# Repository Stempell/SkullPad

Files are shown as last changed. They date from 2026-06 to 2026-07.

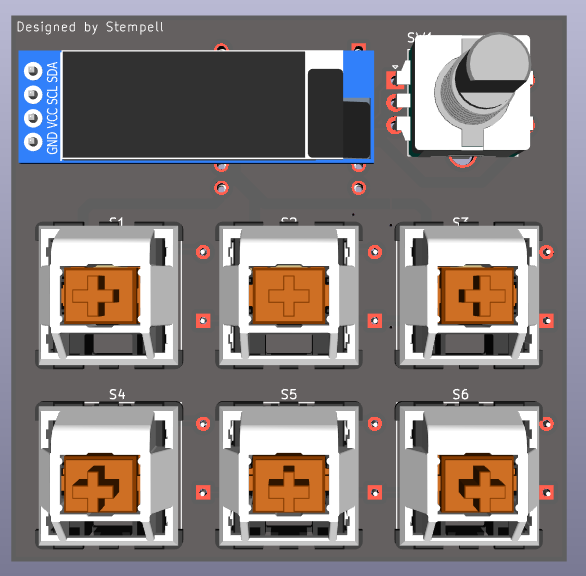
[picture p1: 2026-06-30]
Photos/Zrzut ekranu 2026-06-30 004716.png

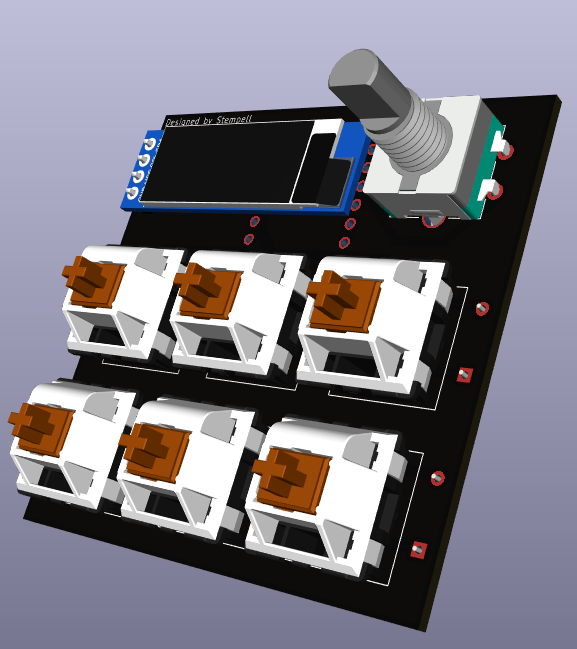
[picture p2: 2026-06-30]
Photos/Zrzut ekranu 2026-06-30 004732.png

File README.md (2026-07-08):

# SkullPad
Im buliding this macropad for Hack Club's stardance program! I'll be using it for shortcuts and volume controll.
Here's how it looks:

Zrzut ekranu 2026-07-08 193353

## Pcb schematic:

Zrzut ekranu 2026-07-06 035041

## Footprint:

Zrzut ekranu 2026-07-06 035101

The Pcb is rectangle with dimentions 61,65mm x 60,60mm

## 3D view:

Zrzut ekranu 2026-06-30 004732
Zrzut ekranu 2026-06-30 004716
Zrzut ekranu 2026-06-30 004722

## Case:

Zrzut ekranu 2026-06-29 221610
Zrzut ekranu 2026-06-29 221618

the case dimensions are 76,7mm x 75,6mm, excluding the corner chamferings

## Used libraries:
Joe Scotto's ScottoKicad - https://github.com/joe-scotto/scottokeebs/tree/main/Extras/ScottoKicad

Hack Club's KiCAD care package - https://github.com/hackclub/hackpad/releases/tag/v0.1-bugfix

## Bill OF Materials:
  
  1x xiao RP2040
  
  6x mx-style switches
  
  6x black keycaps
  
  6x through-hole 1N4148 diodes
  
  1x EC11 rotary encoder
  
  4x M3x16mm screws
  
  4x M3x5mx4mm heatset inserts
  
  1x 0.91 inch OLED display
  
  1x printed 61,7 x 60,6 circut board
  
  1x 3d printed case shell
  
  1x 3d printed case bottom plate

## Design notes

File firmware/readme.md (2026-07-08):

# skullpad
Im buliding this macropad for Hack Club's stardance program! I'll be using it for shortcuts and volume controll. The Keys work as shown:

 ┌───┬───┬───┐			Key A - Win + E (opens file explorer)
 
 │  A │  B │  C │			Key B - Ctrl + M (it mutes my discord mic)
 
 ├───┼───┼───┤			Key C - Delete Key
 
 │  D │  E │  F │			Key D - Previous track
 
 └───┴───┴───┘			Key E - Play / Pause
 
			    		Key F - Next track

* Keyboard Maintainer: [Wiktor Stępień](https://github.com/Stempell)

Make example for this keyboard (after setting up your build environment):

    make skullpad:default

Flashing example for this keyboard:

    make skullpad:default:flash

See the [build environment setup](https://docs.qmk.fm/#/getting_started_build_tools) and the [make instructions](https://docs.qmk.fm/#/getting_started_make_guide) for more information. Brand new to QMK? Start with our [Complete Newbs Guide](https://docs.qmk.fm/#/newbs).

## Bootloader

Enter the bootloader in 3 ways:

* **Bootmagic reset**: Hold down the key at (0,0) in the matrix (usually the top left key or Escape) and plug in the keyboard
* **Physical reset button**: Briefly press the button on the back of the PCB - some may have pads you must short instead
* **Keycode in layout**: Press the key mapped to `QK_BOOT` if it is available

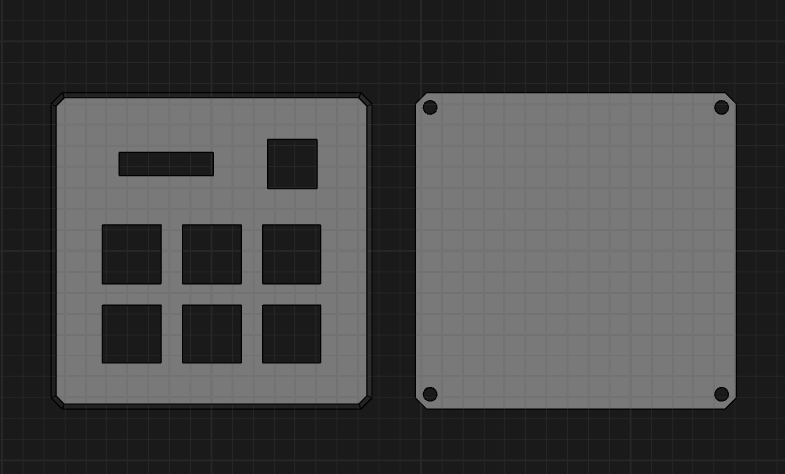
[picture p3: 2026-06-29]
Photos/Zrzut ekranu 2026-06-29 221618.png

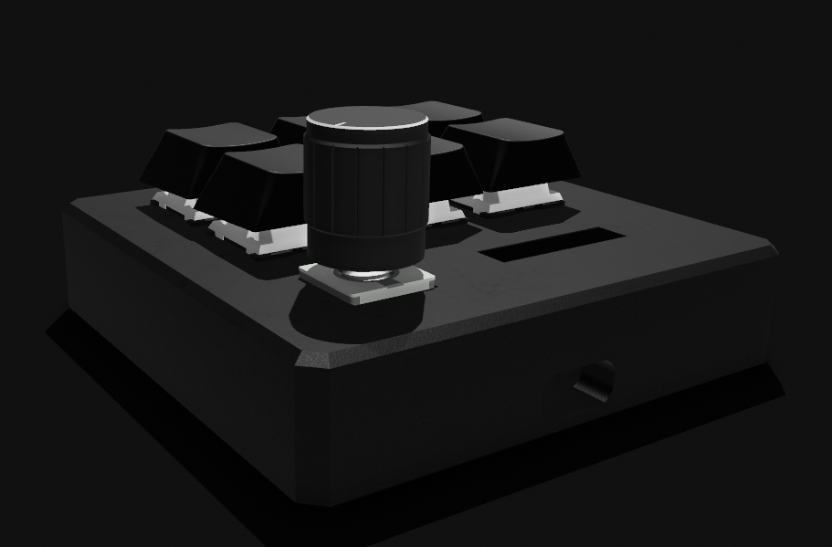
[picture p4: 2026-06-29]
Photos/Zrzut ekranu 2026-06-29 214808.png

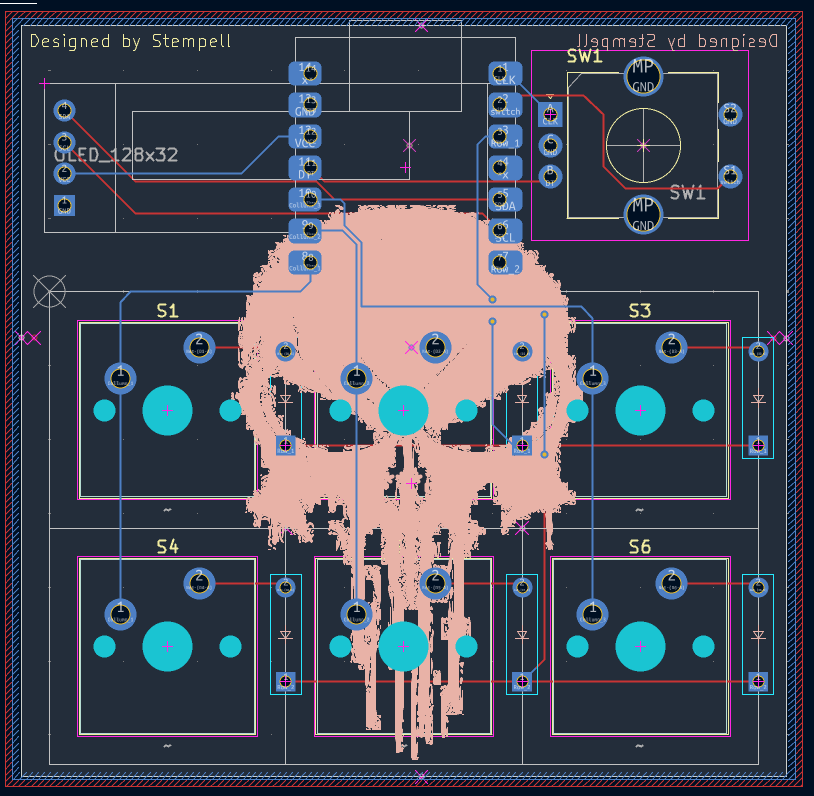
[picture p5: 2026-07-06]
Photos/Zrzut ekranu 2026-07-06 035101.png

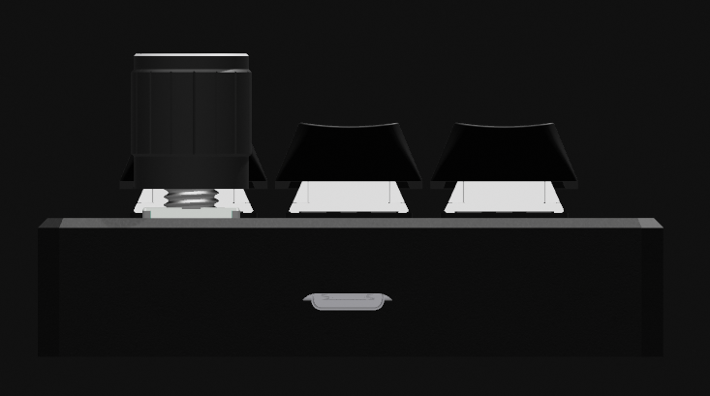
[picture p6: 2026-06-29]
Photos/Zrzut ekranu 2026-06-29 214815.png

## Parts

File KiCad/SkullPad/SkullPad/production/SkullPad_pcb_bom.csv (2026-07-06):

Designator | Footprint | Quantity | Value | LCSC Part #
D1, D2, D3, D4, D5, D6 | Diode_DO-35 | 6 | ~
J2 | OLED_128x32 | 1 | OLED_128x32
S1, S2, S3, S4, S5, S6 | MX_PCB_1.00u | 6 | ~
SW1 | RotaryEncoder_Alps_EC11E-Switch_Vertical_H20mm_CircularMountingHoles | 1 | RotaryEncoder_Switch_MP
U1 | Seeed_XIAO_RP2040 | 1 | XIAO-RP2040-DIP

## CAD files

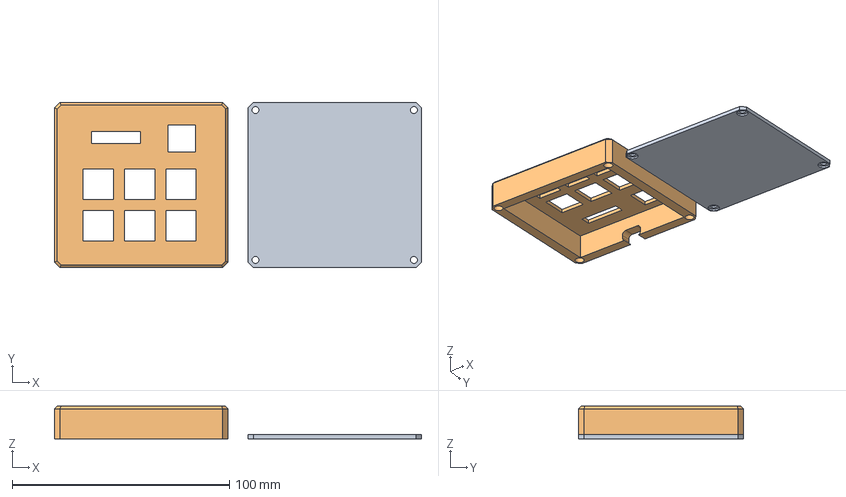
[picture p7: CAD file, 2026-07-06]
.STEP's/SkullPad_caseFull.step
168.9 x 76.0 x 15.0 mm
Rotary Encoder - KY-040 v2:1
Magnet Mounting:1
Magnet:1
MagneticEncoder_AS5600 v2:1
Enclosure:1
Stainless Steel Thin-Profile Hex Nut:1
Stainless Steel Cup-Point Set Screw:1
Stainless Steel Pan Head Phillips Screws:1
r2_100.STEP x 2
r1_100.STEP
MX_PCB x 6
OLED_0.91_128x32
Pin Header 4 x 1 TH 2.54mm Pitch
RESC-0603 x 13
2SD0601A
EC11
Diode_DO-35 x 6
Seeed_XIAO_RP2040
Stardance macropad_PCB
0ea79a684b4664d49b78a8667e167800f789ac8b_switch

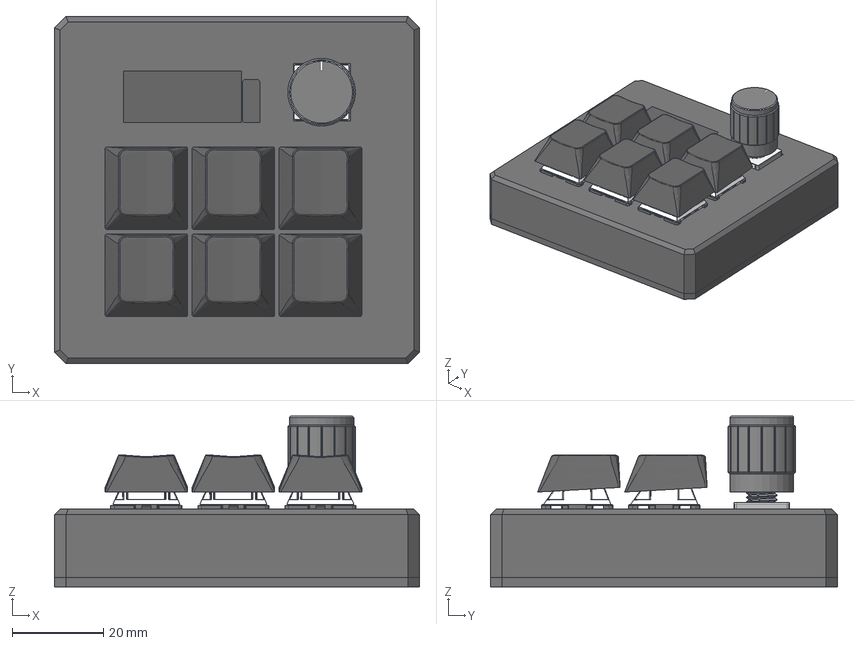
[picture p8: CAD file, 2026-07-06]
CAD/SkullPad_fullProduct.step
79.9 x 76.0 x 37.3 mm
Rotary Encoder - KY-040 v2:1
Magnet Mounting:1
Magnet:1
MagneticEncoder_AS5600 v2:1
Enclosure:1
Stainless Steel Thin-Profile Hex Nut:1
Stainless Steel Cup-Point Set Screw:1
Stainless Steel Pan Head Phillips Screws:1
r2_100.STEP x 2
r1_100.STEP
MX_PCB x 6
OLED_0.91_128x32
Pin Header 4 x 1 TH 2.54mm Pitch
RESC-0603 x 13
2SD0601A
EC11
Diode_DO-35 x 6
Seeed_XIAO_RP2040
Stardance macropad_PCB
0ea79a684b4664d49b78a8667e167800f789ac8b_switch

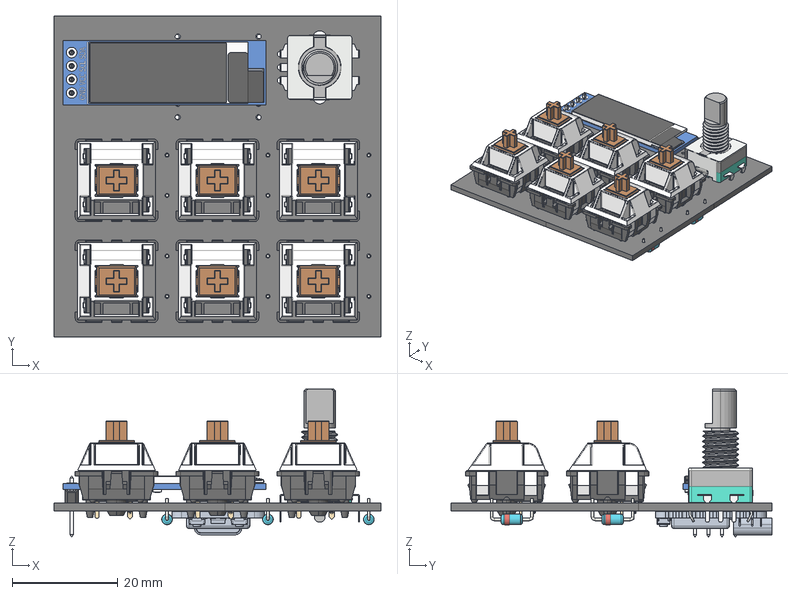
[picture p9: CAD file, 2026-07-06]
KiCad/SkullPad/SkullPad/.step
61.6 x 60.6 x 27.8 mm
MX_PCB x 6
OLED_0.91_128x32
Pin Header 4 x 1 TH 2.54mm Pitch
RESC-0603 x 13
2SD0601A
EC11
Diode_DO-35 x 6
Seeed_XIAO_RP2040
Stardance macropad_PCB

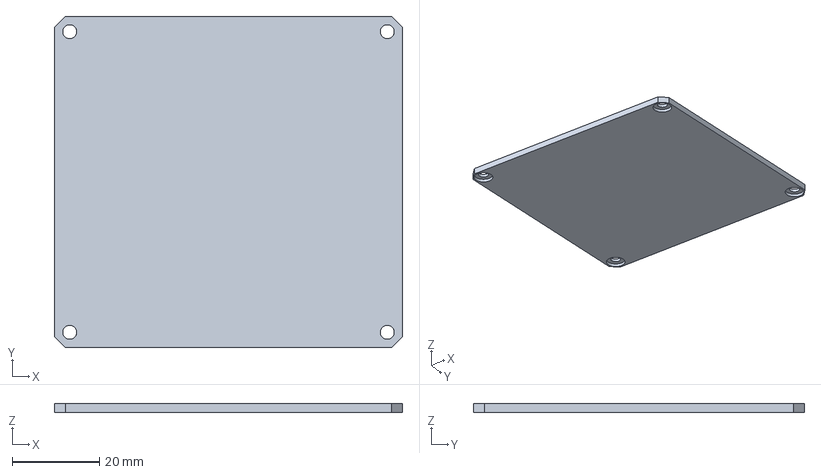
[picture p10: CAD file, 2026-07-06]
Production/Case/SkullPad case bottom plate.step
79.9 x 76.0 x 2.00 mm
Rotary Encoder - KY-040 v2:1
Magnet Mounting:1
Magnet:1
MagneticEncoder_AS5600 v2:1
Enclosure:1
Stainless Steel Thin-Profile Hex Nut:1
Stainless Steel Cup-Point Set Screw:1
Stainless Steel Pan Head Phillips Screws:1
r2_100.STEP x 2
r1_100.STEP
MX_PCB x 6
OLED_0.91_128x32
Pin Header 4 x 1 TH 2.54mm Pitch
RESC-0603 x 13
2SD0601A
EC11
Diode_DO-35 x 6
Seeed_XIAO_RP2040
Stardance macropad_PCB
0ea79a684b4664d49b78a8667e167800f789ac8b_switch

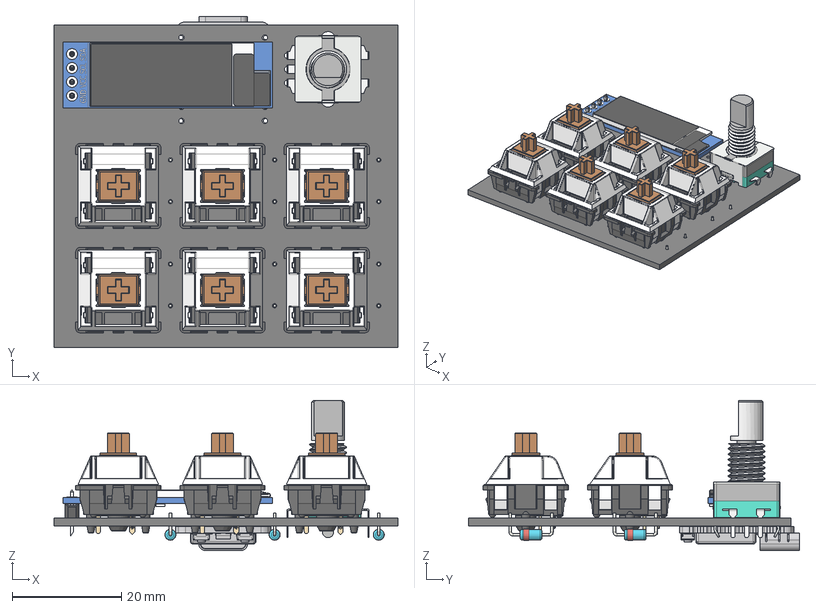
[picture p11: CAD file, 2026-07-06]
.STEP's/SkullPad pcb.step
62.9 x 60.6 x 27.5 mm
Rotary Encoder - KY-040 v2:1
Magnet Mounting:1
Magnet:1
MagneticEncoder_AS5600 v2:1
Enclosure:1
Stainless Steel Thin-Profile Hex Nut:1
Stainless Steel Cup-Point Set Screw:1
Stainless Steel Pan Head Phillips Screws:1
r2_100.STEP x 2
r1_100.STEP
MX_PCB x 6
OLED_0.91_128x32
Pin Header 4 x 1 TH 2.54mm Pitch
RESC-0603 x 13
2SD0601A
EC11
Diode_DO-35 x 6
Seeed_XIAO_RP2040
Stardance macropad_PCB
0ea79a684b4664d49b78a8667e167800f789ac8b_switch

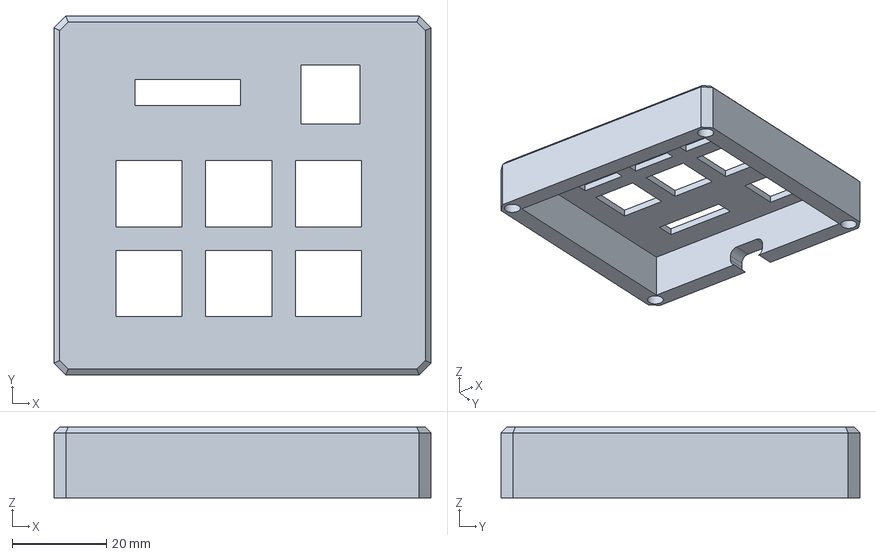
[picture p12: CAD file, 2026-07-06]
Production/Case/SkullPad case shell.step
79.9 x 76.0 x 15.0 mm
Rotary Encoder - KY-040 v2:1
Magnet Mounting:1
Magnet:1
MagneticEncoder_AS5600 v2:1
Enclosure:1
Stainless Steel Thin-Profile Hex Nut:1
Stainless Steel Cup-Point Set Screw:1
Stainless Steel Pan Head Phillips Screws:1
r2_100.STEP x 2
r1_100.STEP
MX_PCB x 6
OLED_0.91_128x32
Pin Header 4 x 1 TH 2.54mm Pitch
RESC-0603 x 13
2SD0601A
EC11
Diode_DO-35 x 6
Seeed_XIAO_RP2040
Stardance macropad_PCB
0ea79a684b4664d49b78a8667e167800f789ac8b_switch

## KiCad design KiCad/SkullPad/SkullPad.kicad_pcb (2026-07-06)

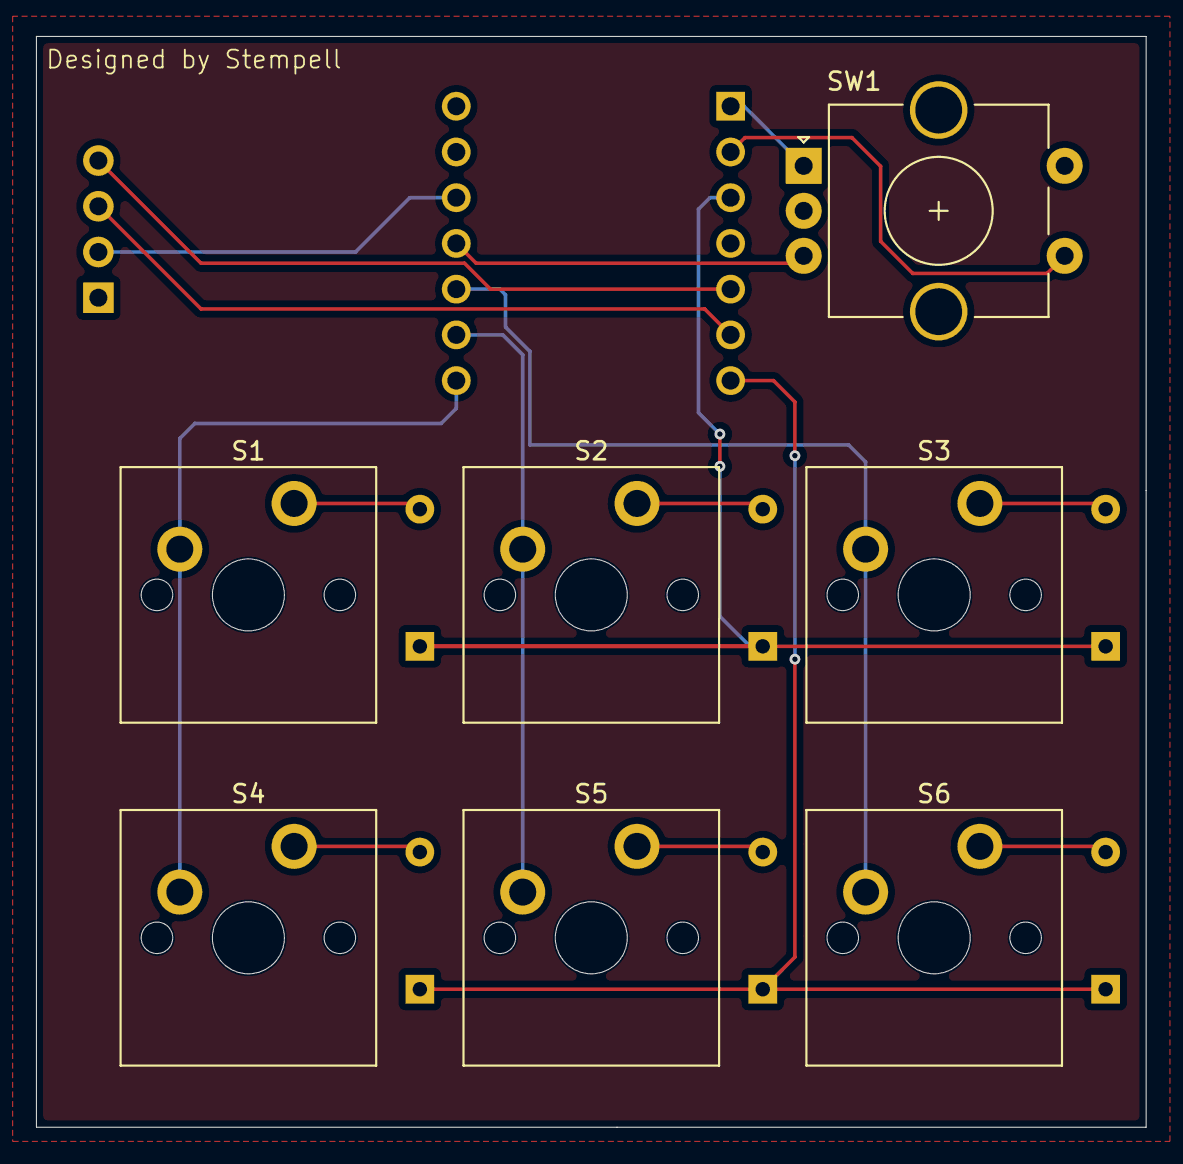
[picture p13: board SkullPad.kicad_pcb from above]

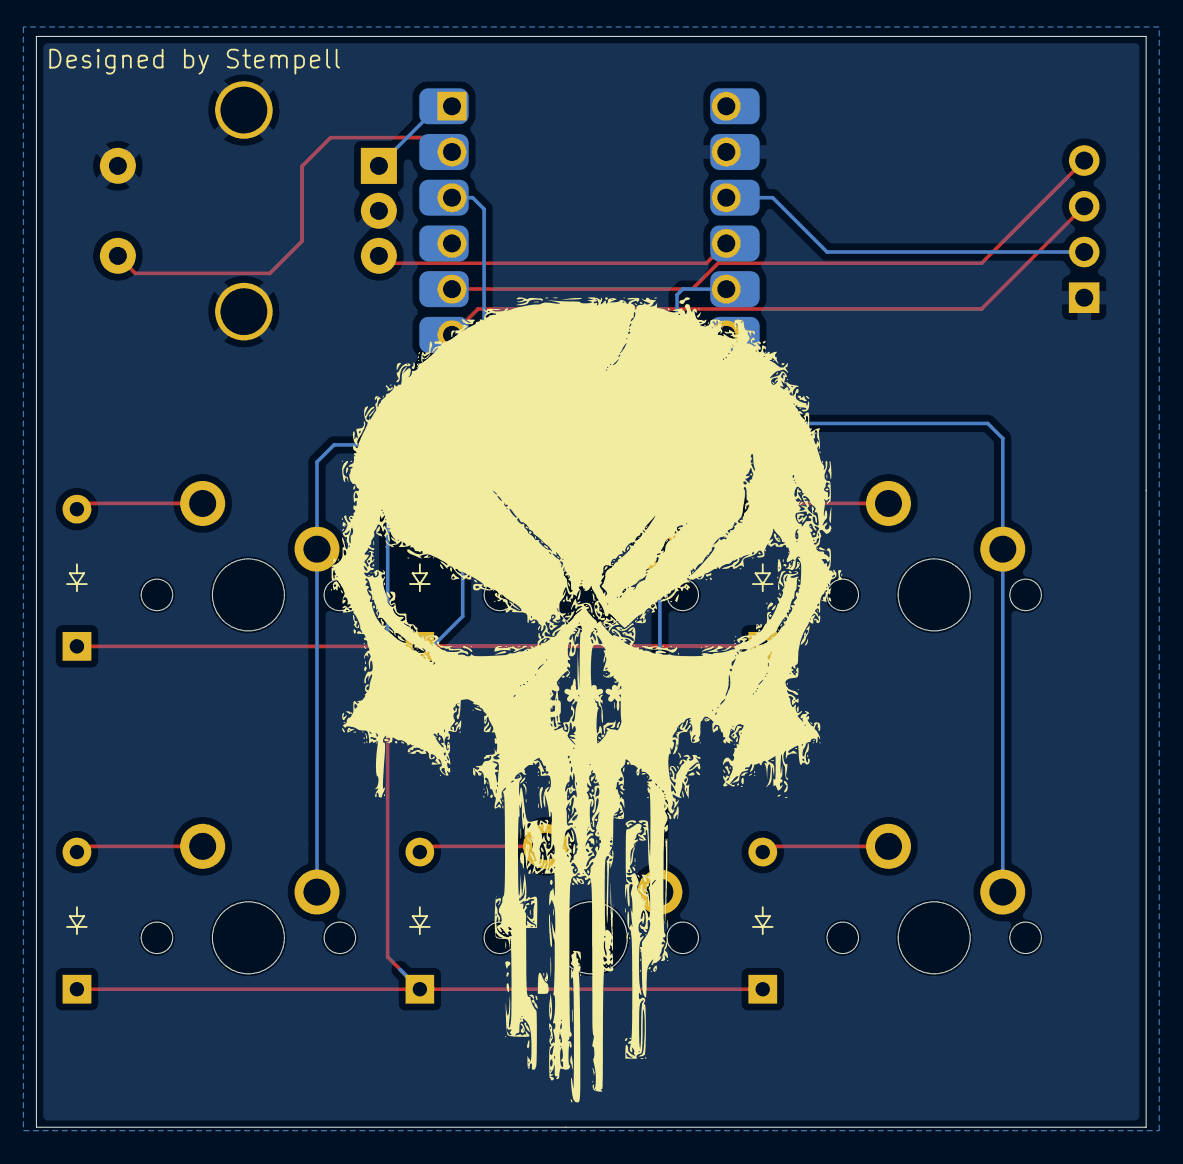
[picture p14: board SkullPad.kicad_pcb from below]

Board: 2 copper layers, 61.6 x 60.6 mm, 15 parts (7 on the bottom side), 18 nets.

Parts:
D1, D2, D3, D4, D5, D6: Diode_DO-35
J2: OLED_128x32
S1, S2, S3, S4, S5, S6: MX_PCB_1.00u
SW1: RotaryEncoder_Switch_MP; RotaryEncoder_Alps_EC11E-Switch_Vertical_H20mm_CircularMoun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
U1: XIAO-RP2040-DIP; Seeed_XIAO_RP2040

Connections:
CLK: SW1.A, U1.1 (P26_A0_D0)
Collumn_1: S1.1, S4.1, U1.8 (P1_D7_RX)
Collumn_2: S2.1, S5.1, U1.9 (P2_D8_SCK)
Collumn_3: S3.1, S6.1, U1.10 (P4_D9_MISO)
DT: SW1.B, U1.11 (P3_D10_MOSI)
GND: J2.1 (GND), SW1.C, SW1.MP, SW1.S2, U1.13 (GND)
unnamed: D1.2 (A), S1.2
unnamed: D2.2 (A), S2.2
unnamed: D3.2 (A), S3.2
unnamed: D4.2 (A), S4.2
unnamed: D5.2 (A), S5.2
unnamed: D6.2 (A), S6.2
Row_1: D1.1 (K), D2.1 (K), D3.1 (K), U1.3 (P28_A2_D2)
Row_2: D4.1 (K), D5.1 (K), D6.1 (K), U1.7 (P0_D6_TX)
SCL: J2.3 (SCL), U1.6 (P7_SCL_D5)
SDA: J2.4 (SDA), U1.5 (P6_SDA_D4)
VCC: J2.2 (VCC), U1.12 (3V3)
switch: SW1.S1, U1.2 (P27_A1_D1)

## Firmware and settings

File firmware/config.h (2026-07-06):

#pragma once

#define I2C_DRIVER I2CD1
#define I2C1_SDA_PIN GP6
#define I2C1_SCL_PIN GP7
#define OLED_BRIGHTNESS 128

#define ENCODER_A_PINS {GP26}
#define ENCODER_B_PINS {GP3}

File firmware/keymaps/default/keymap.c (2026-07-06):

// Copyright 2023 QMK
// SPDX-License-Identifier: GPL-2.0-or-later

#include QMK_KEYBOARD_H

enum layers {
    _BASE
};

const uint16_t PROGMEM encoder_map[][NUM_ENCODERS][NUM_DIRECTIONS] = {
    [_BASE] = {
        ENCODER_CCW_CW(KC_VOLD, KC_VOLU)
    }
};
const uint16_t PROGMEM encoder_switch_map[][NUM_ENCODERS] = {
    [0] = {KC_MUTE}
};

#ifdef OLED_ENABLE
bool oled_task_user(void){
    oled_write_ln_P(PSTR("SkullPad"), false);
    oled_write_ln_P(PSTR("Ready"), false);
    return false;
}
#endif

#ifdef OLED_ENABLE
static void render_status(void) {
    oled write_ln_P(PSTR("SkullPad"), false);

    switch(get_highest_layer(layer_state)){
        case 0:
            oled_write_ln_P(PSTR("LAYER: BASE"), false);
            break;
        default:
            oled_write_ln_P(PSTR("vol ctrl active"), false);
    }

    bool oled_task_user(void) {
        render_status();
        return false;
    }
}
#endif


const uint16_t PROGMEM keymaps[][MATRIX_ROWS][MATRIX_COLS] = {
    /*
     * ┌───┬───┬───┐
     * │ A │ B │ C │
     * ├───┼───┼───┤
     * │ D │ E │ F │
     * └───┴───┴───┘
     */
    [0] = LAYOUT_ortho_2x3(
        KC_NO,    LCTL(KC_M),    KC_DEL,
        KC_MPRV,    KC_MPLY,    KC_MNXT
    )
};

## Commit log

2026-06-20 added photos of the pcb
2026-06-29 added bill of materials
2026-06-29 added .STEP's and gerbers
    [SkullPad case bottom plate.step, SkullPad case shell.step, SkullPad_caseFull.step]
2026-06-29 Modified STEP's
    [SkullPad case bottom plate.step, SkullPad case shell.step, SkullPad_caseFull.step]
2026-06-29 Replace images in README.md
    Updated images in the Footprint and 3D view sections.
2026-07-06 small pcb update
2026-07-06 added firmware and updated the production folder
    [SkullPad case bottom plate.step, SkullPad case shell.step, SkullPad pcb.step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]
2026-07-06 KiCad files update
    [.step, SkullPad case bottom plate.step, SkullPad case shell.step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]
